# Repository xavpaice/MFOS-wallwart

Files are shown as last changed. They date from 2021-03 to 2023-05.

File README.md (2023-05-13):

# MFOS-wallwart

Slightly updated MFOS wallwart power supply for Eurorack, adding a +5V rail.

V0.1 dev version

This schematic and PCB is written using Kicad, v6.0.2

For the original circuit, see http://musicfromouterspace.com/analogsynth_new/WALLWARTSUPPLY/WALLWARTSUPPLY.php.

Though I have used insanely thick traces, the actual rating of the circuit with
stated components is about 1A total.  If you need more, consider something more
expensive.

The information in this repository is provided in good faith but no
responsibility is accepted for the accuracy or suitability for any purpose; you
use it entirely at your own risk.

Please report errors and omissions at
https://github.com/xavpaice/MFOS-wallwart/issues.

Misuse of electronics can result in nasty things like death, or, worse, fried
Eurorack modules.  Please take care.  Remember to only chew on lead free diodes.

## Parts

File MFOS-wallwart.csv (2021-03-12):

Id | Designator | Package | Quantity | Designation | Supplier and ref
1 | REF** | OSHW-Logo2_9.8x8mm_SilkScreen | 1 | OSHW-Logo2_9.8x8mm_SilkScreen
2 | J3 | PinHeader_2x05_P2.54mm_Vertical | 1 | Conn_02x05_Odd_Even
3 | R3 | R_Axial_DIN0207_L6.3mm_D2.5mm_P10.16mm_Horizontal | 1 | 160
4 | D9 | PinHeader_1x02_P2.54mm_Vertical | 1 | LED
5 | SW1 | PinHeader_1x02_P2.54mm_Vertical | 1 | SW_SPST
6 | J1 | PinHeader_1x02_P2.54mm_Vertical | 1 | Barrel_Jack
7 | D8,D7,D6,D5,D4,D3,D2,D1 | D_DO-41_SOD81_P10.16mm_Horizontal | 8 | 1N4004
8 | C12,C11,C10,C9,C8,C7 | C_Radial_D6.3mm_H5.0mm_P2.50mm | 6 | 1uF
9 | U3 | TO-220-3_Vertical | 1 | L7805
10 | U2 | TO-220-3_Vertical | 1 | L7912
11 | U1 | TO-220-3_Vertical | 1 | L7812
12 | J2 | IDC-Header_2x08_P2.54mm_Vertical | 1
13 | C4,C6,C5,C3,C2,C1 | CP_Radial_D18.0mm_P7.50mm | 6 | 3300uF
14 | R2,R1 | R_Axial_DIN0207_L6.3mm_D2.5mm_P10.16mm_Horizontal | 2 | 3K3

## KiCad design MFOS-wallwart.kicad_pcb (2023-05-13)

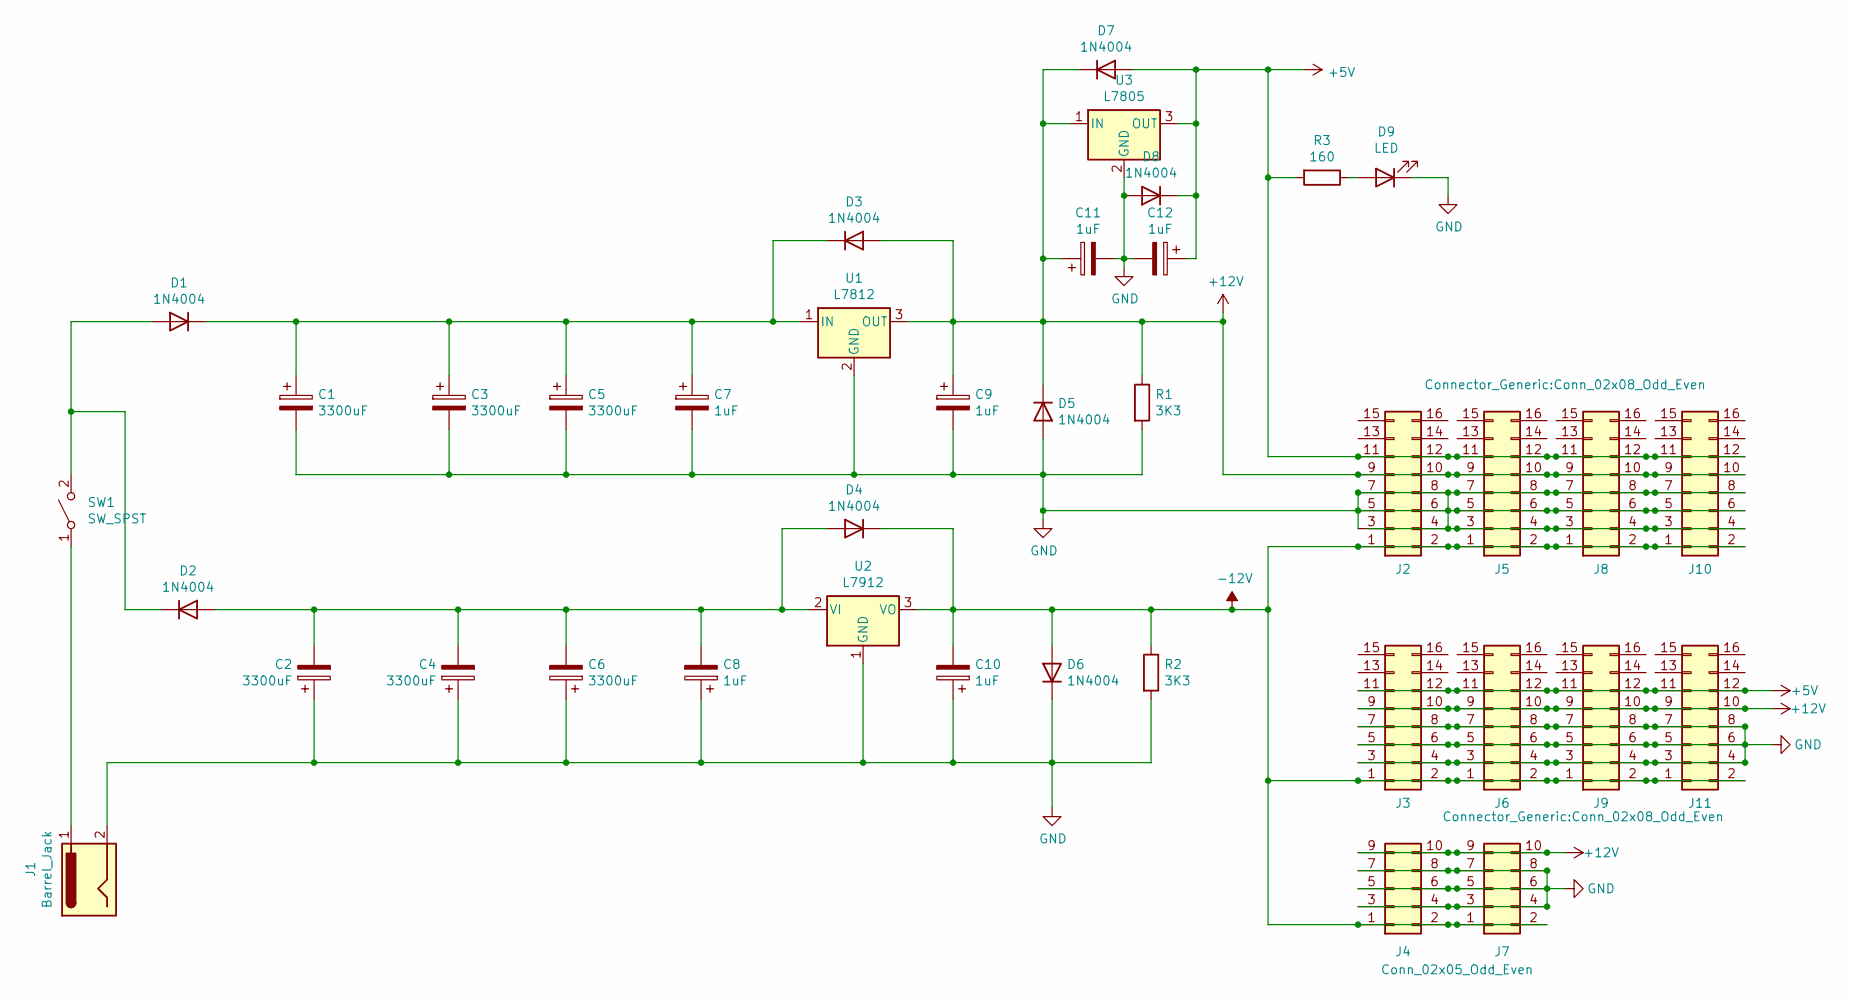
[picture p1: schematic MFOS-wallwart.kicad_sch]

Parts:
C1, C2, C3, C4, C5, C6: 3300uF; CP_Radial_D18.0mm_P7.50mm
C7, C8, C9, C10, C11, C12: 1uF; CP_Radial_D6.3mm_P2.50mm
D1, D2, D3, D4, D5, D6, D7, D8: 1N4004; D_DO-41_SOD81_P10.16mm_Horizontal
D9: LED; PinHeader_1x02_P2.54mm_Vertical
J1: Barrel_Jack; PinHeader_1x02_P2.54mm_Vertical
J2, J3, J5, J6, J8, J9, J10, J11: Connector_Generic:Conn_02x08_Odd_Even; IDC-Header_2x08_P2.54mm_Vertical
J4, J7: Conn_02x05_Odd_Even; PinHeader_2x05_P2.54mm_Vertical
R1, R2: 3K3; R_Axial_DIN0207_L6.3mm_D2.5mm_P10.16mm_Horizontal
R3: 160; R_Axial_DIN0207_L6.3mm_D2.5mm_P10.16mm_Horizontal
SW1: SW_SPST; PinHeader_1x02_P2.54mm_Vertical
U1: L7812; TO-220-3_Vertical
U2: L7912; TO-220-3_Vertical
U3: L7805; TO-220-3_Vertical

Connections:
+5V: C12.1, D7.2 (A), D8.1 (K), J2.11, J2.12, J3.11, J3.12, J5.11, J5.12, J6.11, J6.12, J8.11, J8.12, J9.11, J9.12, J10.11, J10.12, J11.11, J11.12, R3.2, U3.3 (OUT)
+12V: C9.1, C11.1, D3.2 (A), D5.1 (K), D7.1 (K), J2.9, J2.10, J3.9, J3.10, J4.9, J4.10, J5.9, J5.10, J6.9, J6.10, J7.9, J7.10, J8.9, J8.10, J9.9, J9.10, J10.9, J10.10, J11.9, J11.10, R1.1, U1.3 (OUT), U3.1 (IN)
-12V: C10.2, D4.1 (K), D6.2 (A), J2.1, J2.2, J3.1, J3.2, J4.1, J4.2, J5.1, J5.2, J6.1, J6.2, J7.1, J7.2, J8.1, J8.2, J9.1, J9.2, J10.1, J10.2, J11.1, J11.2, R2.1, U2.3 (VO)
GND: C1.2, C2.1, C3.2, C4.1, C5.2, C6.1, C7.2, C8.1, C9.2, C10.1, C11.2, C12.2, D5.2 (A), D6.1 (K), D8.2 (A), D9.1 (K), J1.2, J2.3, J2.4, J2.5, J2.6, J2.7, J2.8, J3.3, J3.4, J3.5, J3.6, J3.7, J3.8, J4.3, J4.4, J4.5, J4.6, J4.7, J4.8, J5.3, J5.4, J5.5, J5.6, J5.7, J5.8, J6.3, J6.4, J6.5, J6.6, J6.7, J6.8, J7.3, J7.4, J7.5, J7.6, J7.7, J7.8, J8.3, J8.4, J8.5, J8.6, J8.7, J8.8, J9.3, J9.4, J9.5, J9.6, J9.7, J9.8, J10.3, J10.4, J10.5, J10.6, J10.7, J10.8, J11.3, J11.4, J11.5, J11.6, J11.7, J11.8, R1.2, R2.2, U1.2 (GND), U2.1 (GND), U3.2 (GND)
unnamed: C1.1, C3.1, C5.1, C7.1, D1.1 (K), D3.1 (K), U1.1 (IN)
unnamed: C2.2, C4.2, C6.2, C8.2, D2.2 (A), D4.2 (A), U2.2 (VI)
unnamed: D1.2 (A), D2.1 (K), SW1.2 (B)
unnamed: D9.2 (A), R3.1
unnamed: J1.1, SW1.1 (A)

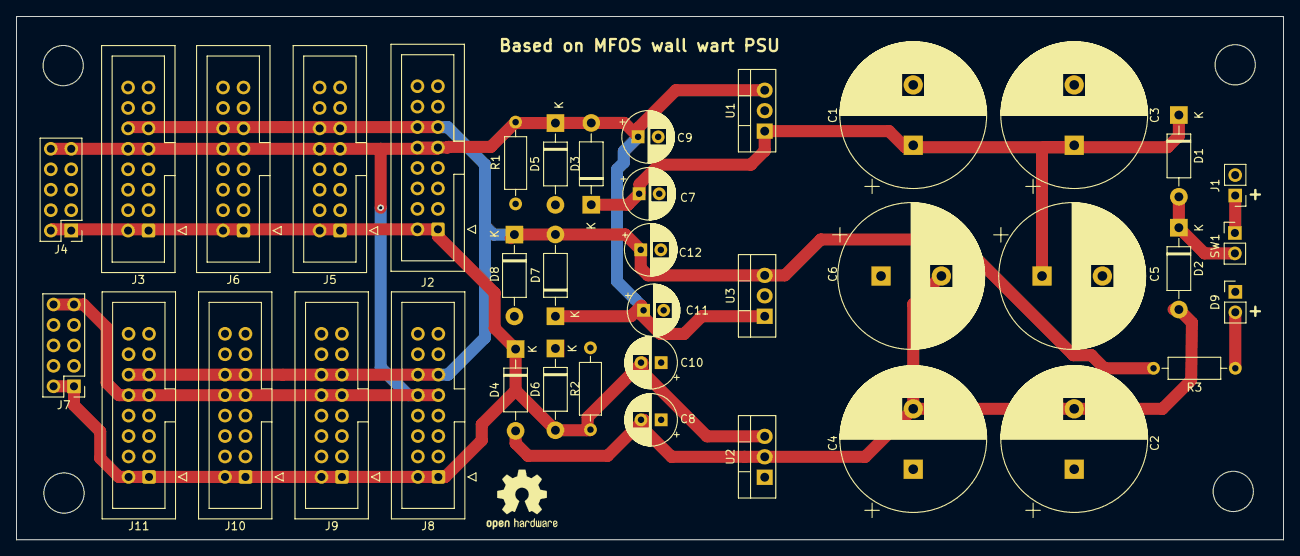
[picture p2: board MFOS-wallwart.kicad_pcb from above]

Board: 2 copper layers, 157.4 x 65.0 mm, 39 parts (0 on the bottom side), 9 nets.

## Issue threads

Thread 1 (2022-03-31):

about the polarity marking of 1uF capacitor,

ws786873, 2022-03-31:
I used 1uF tantalum capacitors. They seem to have polarity and are also marked in the original version. So can you add them? Although I succeeded in making a power supply after trying to read the schematic diagram, before I succeeded, I saw the magic smoke XD

xavpaice, 2023-05-13:
Thanks for the report.  Sorry it took me ages, but I got to make another one and am using polarized caps like you.  I've put the markings on the board and updated to the kicad in Ubuntu Jammy.  Note this is untested, if I make smoke I'll fix the board.

Closed 2023-05-13.

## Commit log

2021-03-12 Updated for extra outputs
    [MFOS-wallwart-B_Cu.gbr, MFOS-wallwart-B_Mask.gbr, MFOS-wallwart-B_Paste.gbr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]
2023-05-13 Minor updates, add polarity to 1uf caps
    [MFOS-wallwart-B_Cu.gbr, MFOS-wallwart-B_Mask.gbr, MFOS-wallwart-B_Paste.gbr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]
